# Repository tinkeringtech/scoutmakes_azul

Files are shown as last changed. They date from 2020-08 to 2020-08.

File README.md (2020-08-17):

ScoutMakes Azul

These are the source design files for the ScoutMakes Azul.

The board can be bought at https://www.tindie.com/products/tinkeringtech/scoutmakes-azul/

Designed by TinkeringTech.
License: Creative Commons ShareAlike 3.0 United States (CC BY-SA 3.0 US)
Check license.txt for more information All text above must be included in any redistribution.

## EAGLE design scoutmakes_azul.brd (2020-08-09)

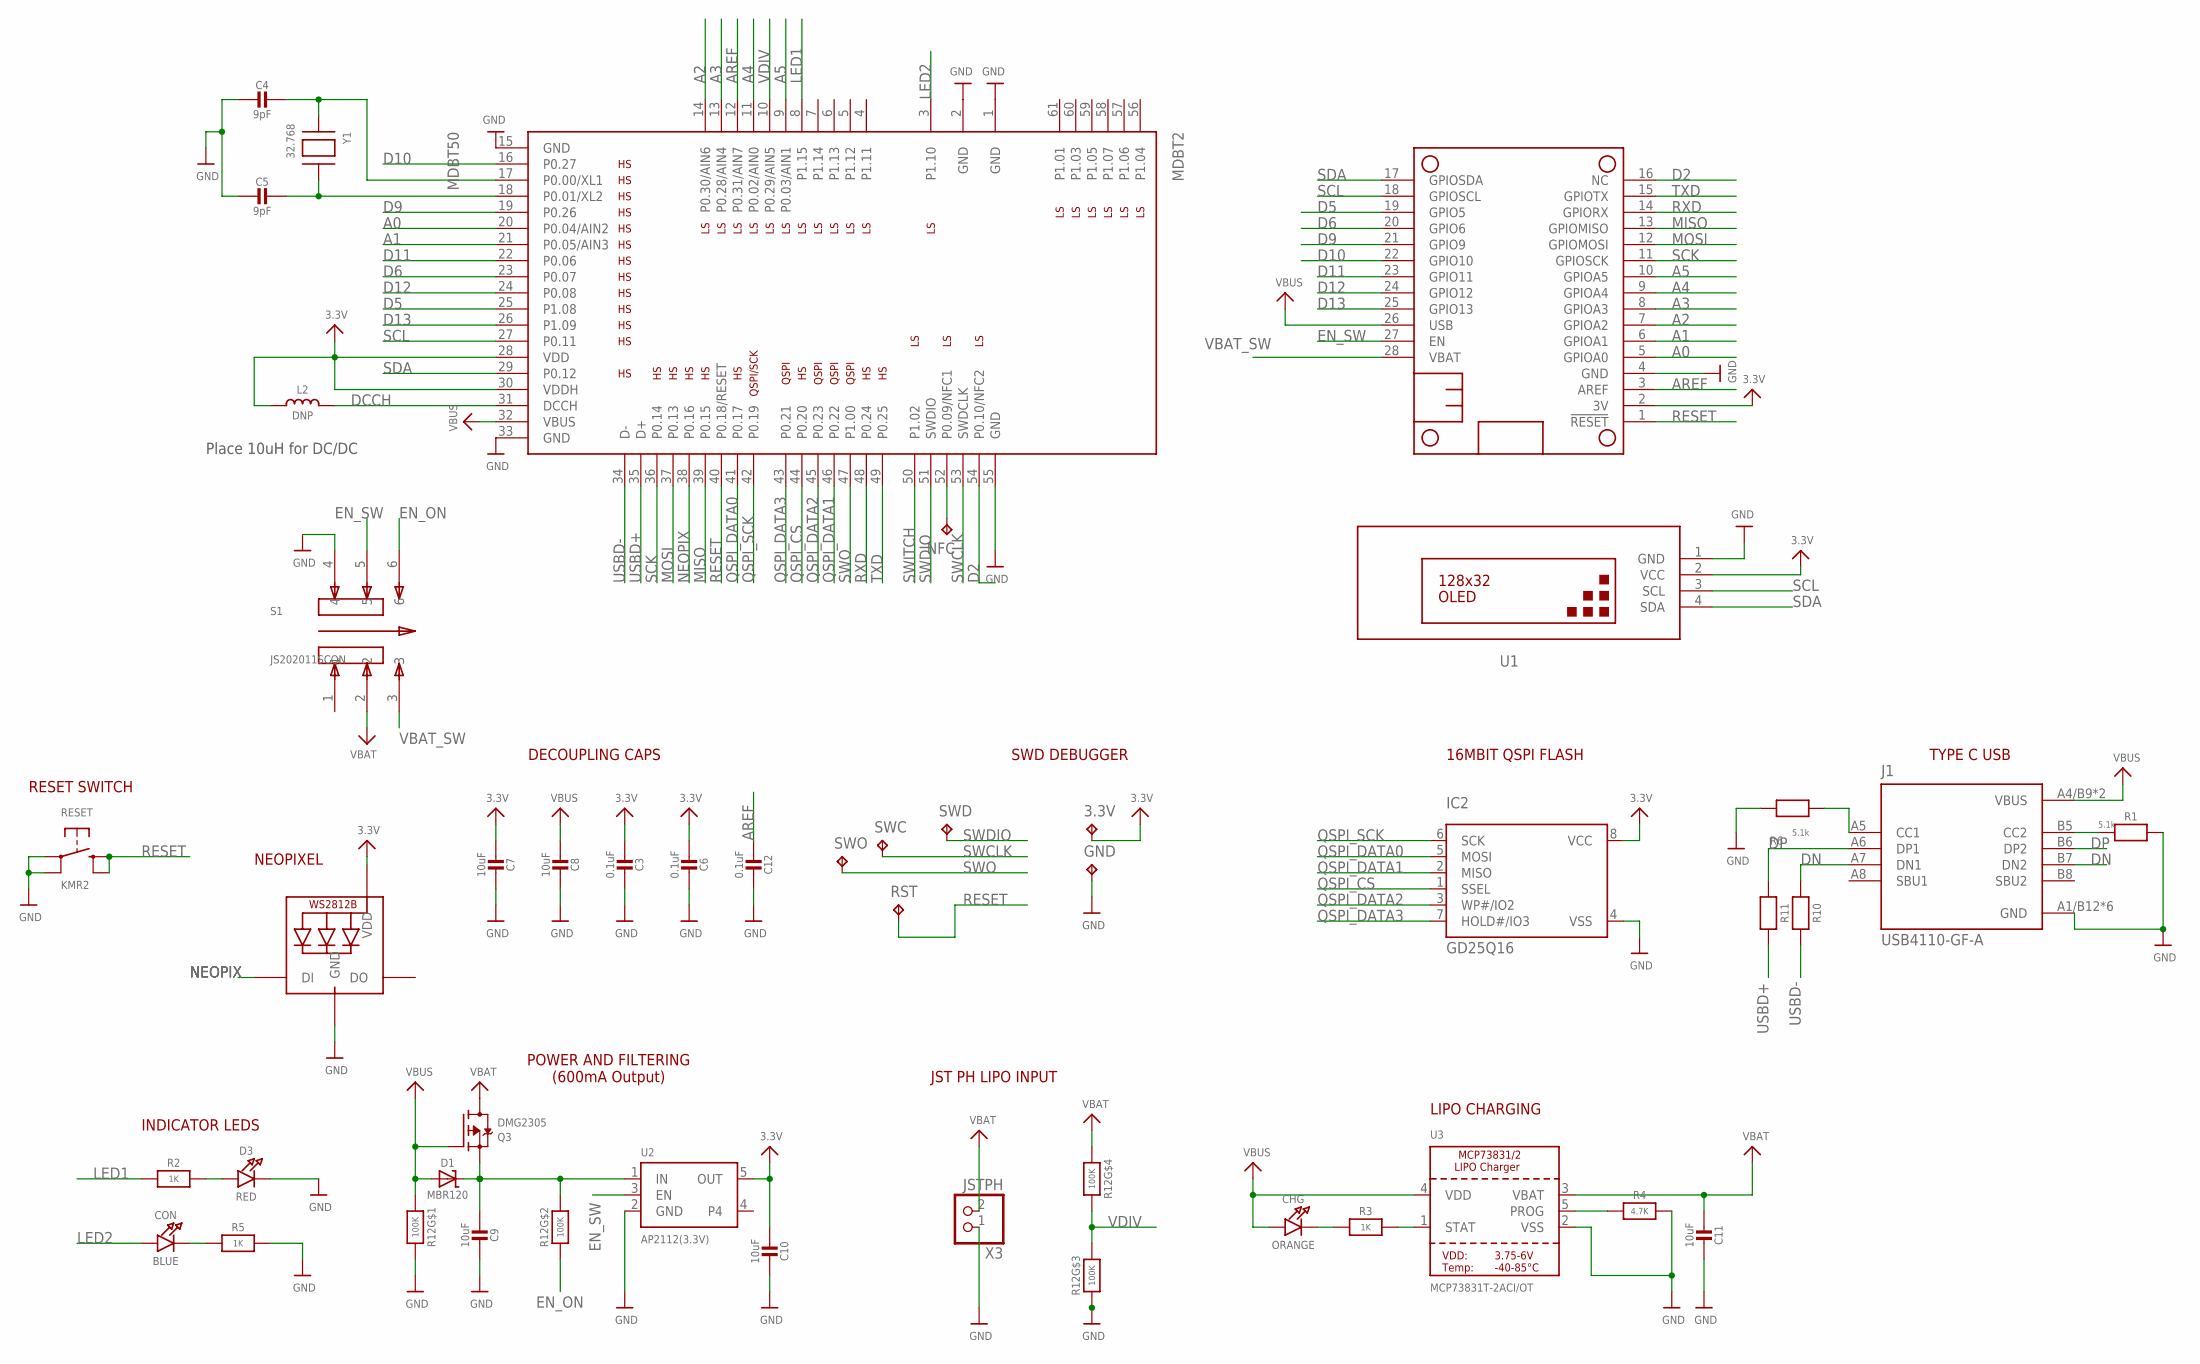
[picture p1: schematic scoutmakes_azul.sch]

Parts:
3.3V: TPTP12R; TP12R
C3, C6, C12: 0.1uF; 0603-NO
C4, C5: 9pF; 0603-NO
C7, C8, C9, C10, C11: 10uF; 0805-NO
CHG: ORANGE; CHIPLED_0805_NOOUTLINE
CON: BLUE; CHIPLED_0805_NOOUTLINE
D1: MBR120; SOD-123
D3: RED; CHIPLED_0805_NOOUTLINE
GND: TPTP12R; TP12R
IC2: GD25Q16; USON8
J1: USB4110-GF-A; GCT_USB4110-GF-A
L2: DNP; _0805MP
LED: WS2812B3535; LED3535
MDBT2: MDBT50
MS1: FEATHERWING_NODIM
NFC: TPTP10R; TP10R
Q3: DMG2305; SOT23-R
R1, R6: 5.1k; 0603-NO
R2, R3, R5: 1K; 0603-NO
R4: 4.7K; 0603-NO
R10, R11: 22; 0603-NO
R12: 100K; RESPACK_4X0603
RESET: KMR2; BTN_KMR2_4.6X2.8
RST: TPTP12R; TP12R
S1: JS202011SCQN; SW_JS202011SCQN
SWC: TPTP12R; TP12R
SWD: TPTP12R; TP12R
SWO: TPTP12R; TP12R
U1: DISPLAY-OLED-128X32
U2: AP2112(3.3V); SOT23-5
U3: MCP73831T-2ACI/OT; SOT23-5
X3: JSTPH; JSTPH2
Y1: 32.768; XTAL3215

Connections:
3.3V: 3.3V.TP, C3.2, C6.2, C7.2, C10.2, IC2.8 (VCC), L2.1, LED.2 (VDD), MDBT2.28 (VDD), MDBT2.30 (VDDH), MS1.2 (3V), U1.2 (VCC), U2.5 (OUT)
A0: MDBT2.20 (P0.04/AIN2), MS1.5 (GPIOA0)
A1: MDBT2.21 (P0.05/AIN3), MS1.6 (GPIOA1)
A2: MDBT2.14 (P0.30/AIN6), MS1.7 (GPIOA2)
A3: MDBT2.13 (P0.28/AIN4), MS1.8 (GPIOA3)
A4: MDBT2.11 (P0.02/AIN0), MS1.9 (GPIOA4)
A5: MDBT2.9 (P0.03/AIN1), MS1.10 (GPIOA5)
AREF: C12.2, MDBT2.12 (P0.31/AIN7), MS1.3 (AREF)
D2: MDBT2.54 (P0.10/NFC2), MS1.16 (NC)
D5: MDBT2.25 (P1.08), MS1.19 (GPIO5)
D6: MDBT2.23 (P0.07), MS1.20 (GPIO6)
D9: MDBT2.19 (P0.26), MS1.21 (GPIO9)
D10: MDBT2.16 (P0.27), MS1.22 (GPIO10)
D11: MDBT2.22 (P0.06), MS1.23 (GPIO11)
D12: MDBT2.24 (P0.08), MS1.24 (GPIO12)
D13: MDBT2.26 (P1.09), MS1.25 (GPIO13)
DCCH: L2.2, MDBT2.31 (DCCH)
DN: J1.A7 (DN1), J1.B7 (DN2), R10.1
DP: J1.A6 (DP1), J1.B6 (DP2), R11.1
EN_ON: R12.2 (1), S1.6
EN_SW: MS1.27 (EN), S1.5, U2.3 (EN)
GND: C3.1, C4.2, C5.2, C6.1, C7.1, C8.1, C9.1, C10.1, C11.1, C12.1, D3.C, GND.TP, IC2.4 (VSS), J1.A1/B12 (GND), J1.B1/A12 (GND), J1.S1 (GND), J1.S2 (GND), J1.S3 (GND), J1.S4 (GND), LED.4 (GND), MDBT2.1 (GND), MDBT2.2 (GND), MDBT2.15 (GND), MDBT2.33 (GND), MDBT2.55 (GND), MS1.4 (GND), R1.2, R4.2, R5.2, R6.2, R12.3 (1), R12.8 (2), RESET.A, RESET.A' (P1), S1.4, U1.1 (GND), U2.2 (GND), U3.2 (VSS), X3.1
LED1: MDBT2.8 (P1.15), R2.1
LED2: CON.A, MDBT2.3 (P1.10)
MISO: MDBT2.39 (P0.15), MS1.13 (GPIOMISO)
MOSI: MDBT2.37 (P0.13), MS1.12 (GPIOMOSI)
unnamed: C4.1, MDBT2.17 (P0.00/XL1), Y1.P$1
unnamed: C5.1, MDBT2.18 (P0.01/XL2), Y1.P$2
unnamed: CHG.C, R3.1
unnamed: J1.A5 (CC1), R6.1
unnamed: D3.A, R2.2
unnamed: J1.B5 (CC2), R1.1
unnamed: R3.2, U3.1 (STAT)
unnamed: R4.1, U3.5 (PROG)
unnamed: CON.C, R5.1
NEOPIX: LED.1 (DI), MDBT2.38 (P0.16)
NFC1: MDBT2.52 (P0.09/NFC1), NFC.TP
QSPI_CS: IC2.1 (SSEL), MDBT2.44 (P0.20)
QSPI_DATA0: IC2.5 (MOSI), MDBT2.41 (P0.17)
QSPI_DATA1: IC2.2 (MISO), MDBT2.46 (P0.22)
QSPI_DATA2: IC2.3 (WP#/IO2), MDBT2.45 (P0.23)
QSPI_DATA3: IC2.7 (HOLD#/IO3), MDBT2.43 (P0.21)
QSPI_SCK: IC2.6 (SCK), MDBT2.42 (P0.19)
RESET: MDBT2.40 (P0.18/RESET), MS1.1 (!RESET), RESET.B (S), RESET.B' (S1), RST.TP
RXD: MDBT2.48 (P0.24), MS1.14 (GPIORX)
SCK: MDBT2.36 (P0.14), MS1.11 (GPIOSCK)
SCL: MDBT2.27 (P0.11), MS1.18 (GPIOSCL), U1.3 (SCL)
SDA: MDBT2.29 (P0.12), MS1.17 (GPIOSDA), U1.4 (SDA)
SWCLK: MDBT2.53 (SWDCLK), SWC.TP
SWDIO: MDBT2.51 (SWDIO), SWD.TP
SWITCH: MDBT2.50 (P1.02)
SWO: MDBT2.47 (P1.00), SWO.TP
TXD: MDBT2.49 (P0.25), MS1.15 (GPIOTX)
USBD+: MDBT2.35 (D+), R11.2
USBD-: MDBT2.34 (D-), R10.2
VBAT: C11.2, Q3.3 (D), R12.4 (1), S1.2, U3.3 (VBAT), X3.2
VBAT_SW: MS1.28 (VBAT), S1.3
VBUS: C8.2, CHG.A, D1.A, J1.A4/B9 (VBUS), J1.B4/A9 (VBUS), MDBT2.32 (VBUS), MS1.26 (USB), Q3.1 (G), R12.1, U3.4 (VDD)
VDIV: MDBT2.10 (P0.29/AIN5), R12.5 (2), R12.6 (2)
VHI: C9.2, D1.C, Q3.2 (S), R12.7 (2), U2.1 (IN)

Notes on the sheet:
LIPO CHARGING
POWER AND FILTERING (600mA Output)
JST PH LIPO INPUT
INDICATOR LEDS
RESET SWITCH
DECOUPLING CAPS
SWD DEBUGGER
16MBIT QSPI FLASH
TYPE C USB
Place 10uH for DC/DC
NEOPIXEL

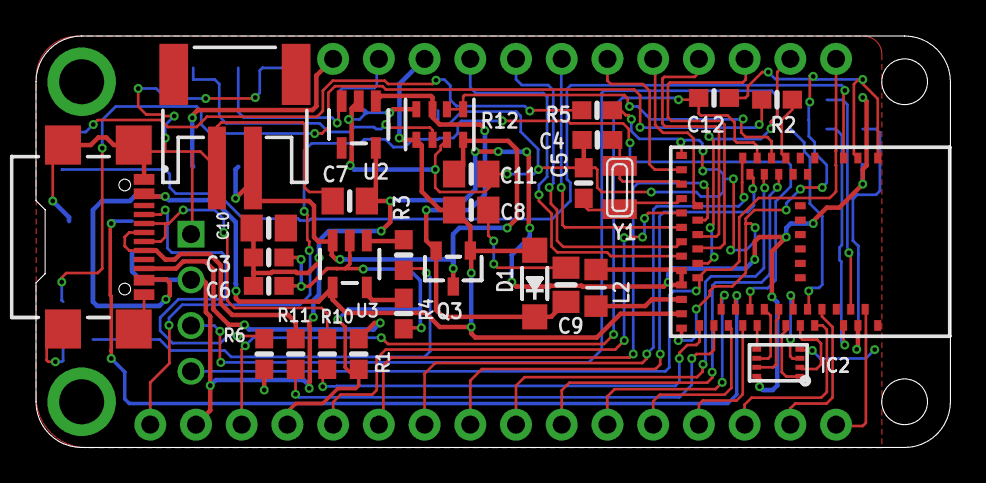
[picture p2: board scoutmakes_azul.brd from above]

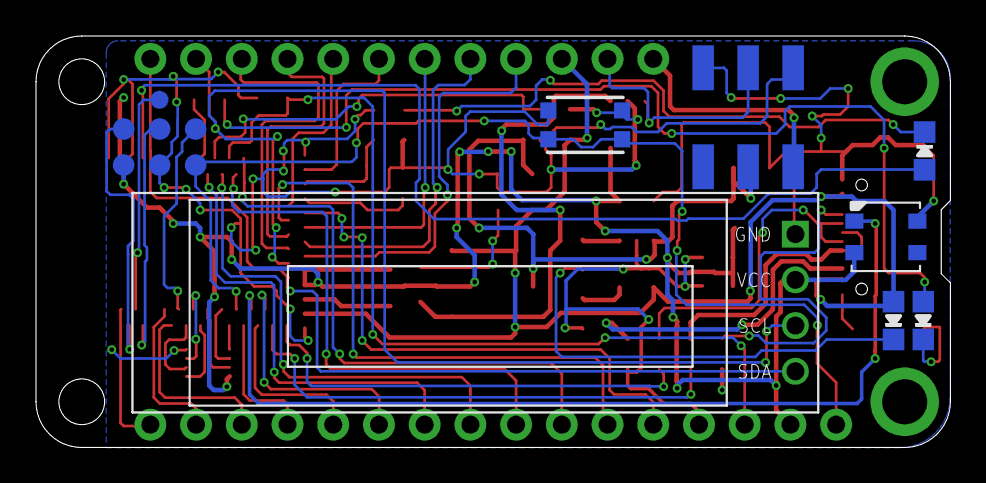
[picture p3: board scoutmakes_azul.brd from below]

Board: 2 copper layers, 50.8 x 22.9 mm, 44 parts (14 on the bottom side), 59 nets.

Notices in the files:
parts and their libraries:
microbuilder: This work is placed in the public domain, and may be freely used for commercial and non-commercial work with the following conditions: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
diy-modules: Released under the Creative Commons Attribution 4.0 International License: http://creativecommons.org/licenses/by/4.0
